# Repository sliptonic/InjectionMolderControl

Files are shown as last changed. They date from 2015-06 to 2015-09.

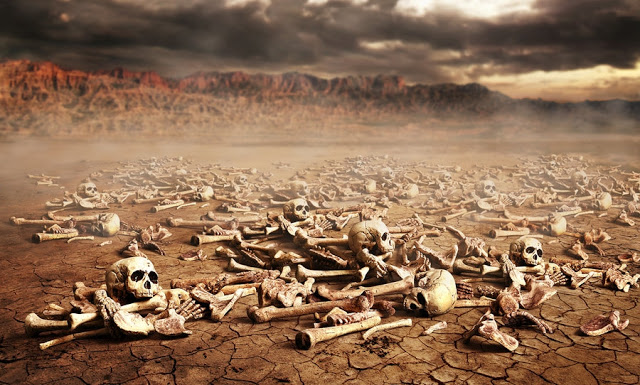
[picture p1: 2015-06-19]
termistortemp2/valley_of_dry_bones_.jpg

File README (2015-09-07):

Injection molder digital control 
Columbia Gadget Works (2015)

This is a control system for a hobby injection molder as described in "Secrets of Building a Plastic Injection Molding Machine" by Vincent R. Gingery.

In the book, he uses a simple thermostat to control a heater element.  We wanted to try something slightly more sophisticated so we built this.

The control is housed in a small project box.  It consists of an arduino Nano on a custom board and connected to:

Two tact switches on D11 and D12 for up/down control of the temperature set point.

A Sparkfun 7-segment serial lcd display (https://www.sparkfun.com/products/11440)  The display shows a:nnn for the actual temperature and p:nnn for the setpoint.

A 10k thermister for measuring temperature of the heater block.

A Sparkfun beefcake relay control kit. (https://www.sparkfun.com/products/11042)

#########################
Status:  
#########################
It works but the interface isn't very responsive.

#########################
TODO:  
#########################

Improve the loop that detects button pushes.  
Allow push/hold for inputing the temperature.

Improve the loop that controls temperature.  PID?

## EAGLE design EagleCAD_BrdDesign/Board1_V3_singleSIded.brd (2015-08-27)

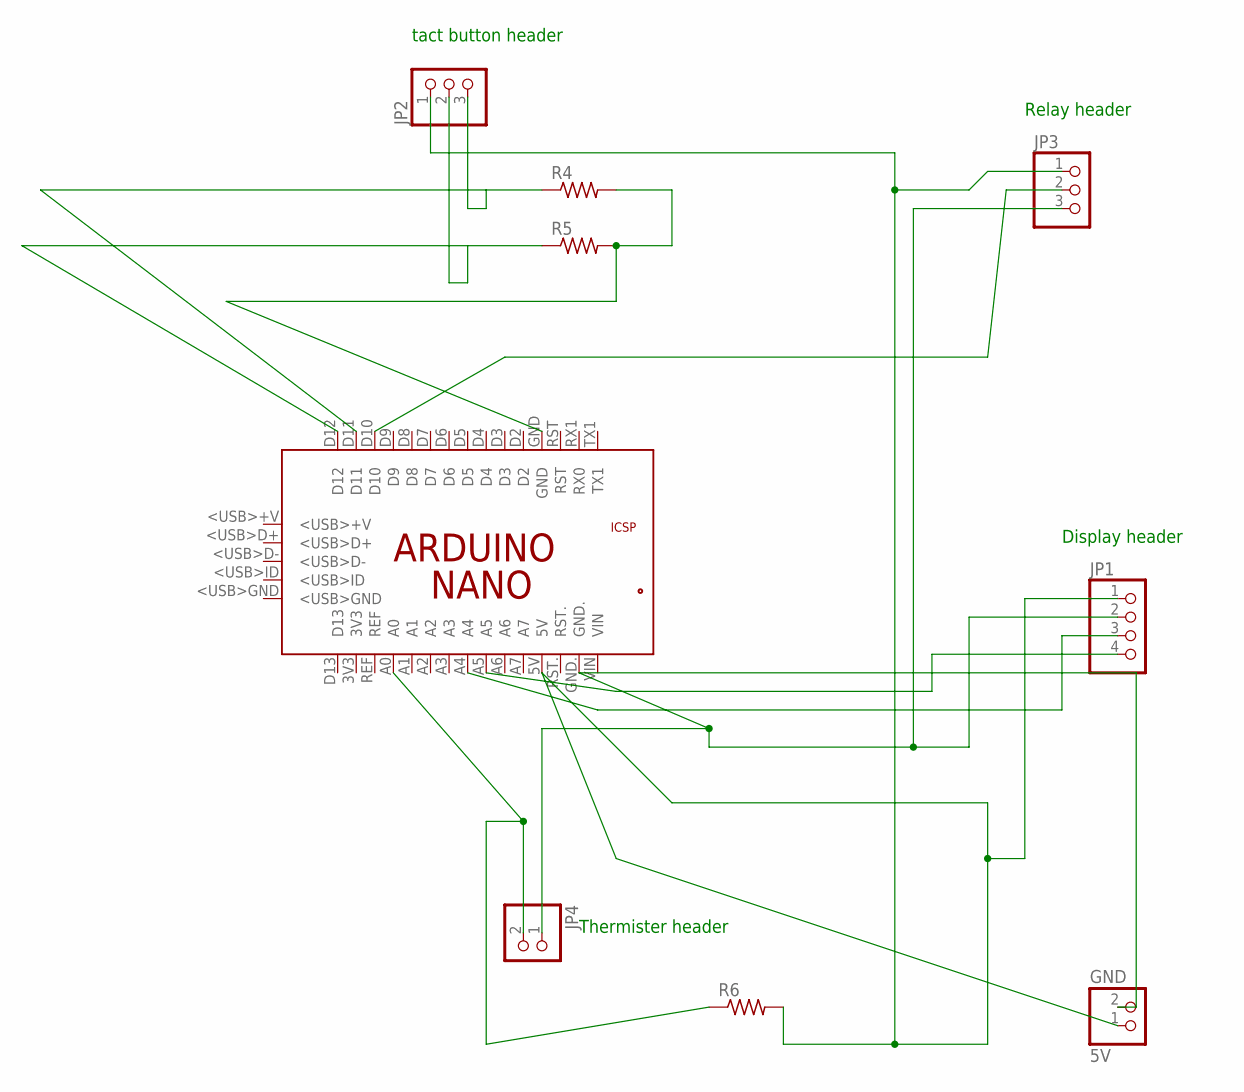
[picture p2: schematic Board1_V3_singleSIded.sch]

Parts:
5V: GND; 1X02/90
JP1: PINHD-1X4/90; 1X04/90
JP2, JP3: PINHD-1X3/90; 1X03/90
JP4: PINHD-1X2/90; 1X02/90
PCB1: ARDUINO_NANO
R4, R5: R-US_0207/10; 0207/10
R6: R-US_0207/15; 0207/15

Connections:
unnamed: JP2.2, PCB1.D12, R5.1
unnamed: JP4.2, PCB1.A0, R6.1
unnamed: JP3.2, PCB1.D10
unnamed: 5V.2, JP1.2, JP3.3, JP4.1, PCB1.GND.
unnamed: JP1.4, PCB1.A5
unnamed: JP1.3, PCB1.A4
unnamed: 5V.1, JP1.1, JP2.1, JP3.1, PCB1.5V, R6.2
unnamed: PCB1.GND, R4.2, R5.2
unnamed: JP2.3, PCB1.D11, R4.1

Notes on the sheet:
tact button header
Thermister header
Display header
Relay header

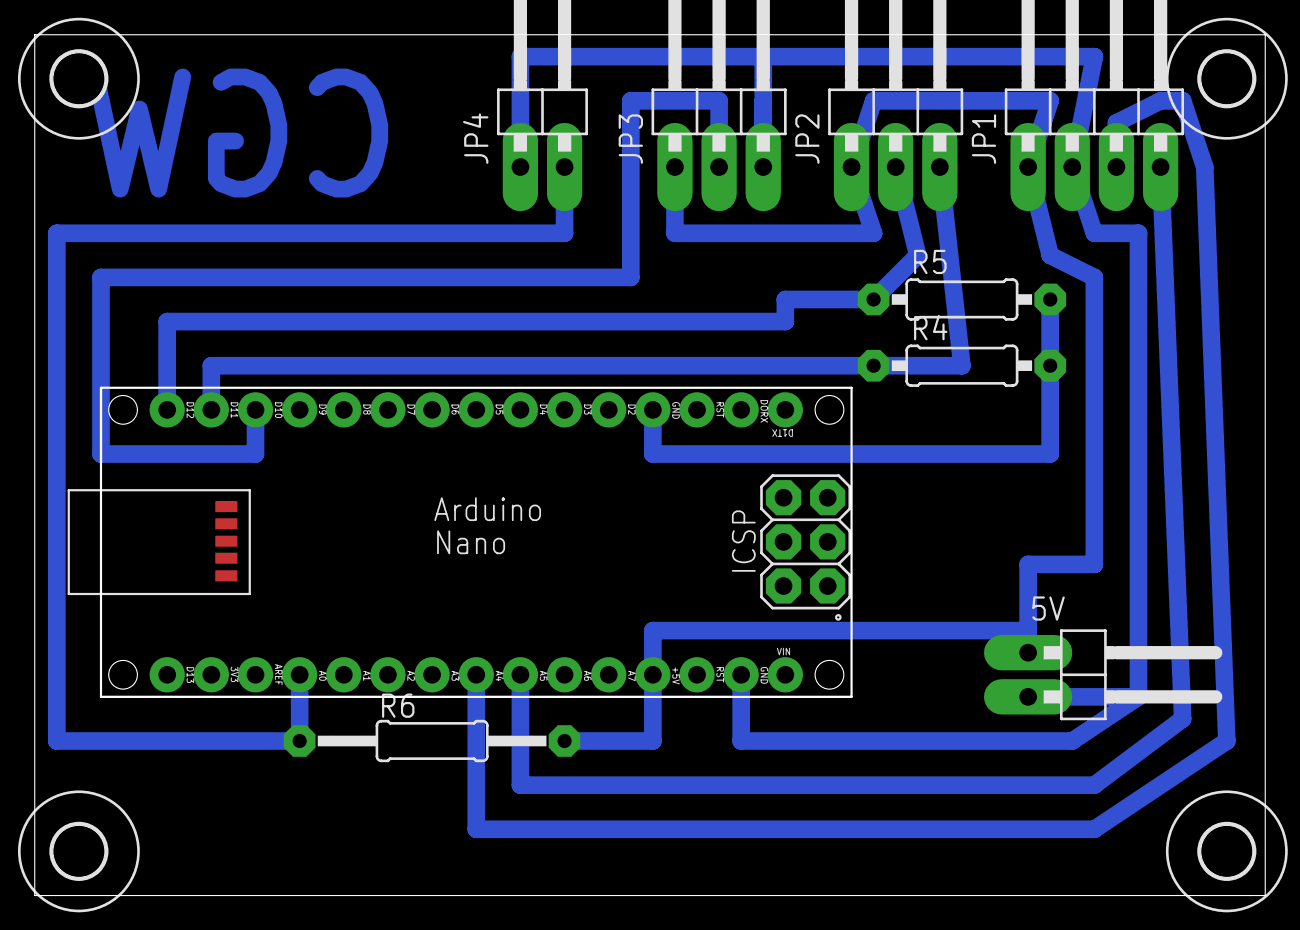
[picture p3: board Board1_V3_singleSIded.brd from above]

Board: 2 copper layers, 70.8 x 49.5 mm, 13 parts (0 on the bottom side), 9 nets.

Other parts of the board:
U$1, U$2, U$3, U$4: 3,0

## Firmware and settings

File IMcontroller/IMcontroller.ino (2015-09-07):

/* Serial 7-Segment Display Example Code

   Circuit:
   Arduino -------------- Serial 7-Segment
     5V   --------------------  VCC
     GND  --------------------  GND
     SDA  --------------------  SDA (A4 on older 'duino's)
     SCL  --------------------  SCL (A5 on older 'duino's)
*/
#include <Wire.h> // Include the Arduino SPI library

// Here we'll define the I2C address of our S7S. By default it
//  should be 0x71. This can be changed, though.
const byte s7sAddress = 0x71;


//Thermistor setup
// which analog pin to connect
#define THERMISTORPIN A0         
// resistance at 25 degrees C
#define THERMISTORNOMINAL 68000      
// temp. for nominal resistance (almost always 25 C)
#define TEMPERATURENOMINAL 31   
// how many samples to take and average, more takes longer
// but is more 'smooth'
#define NUMSAMPLES 5
// The beta coefficient of the thermistor (usually 3000-4000)
#define BCOEFFICIENT 3950
// the value of the 'other' resistor
#define SERIESRESISTOR 10000    

//which pin to connect relay control to
# define RELAYPIN 10
 
int samples[NUMSAMPLES];

//Here's some setup for checking the buttons
#define DEBOUNCE 10  // button debouncer, how many ms to debounce, 5+ ms is usually plenty

// here is where we define the buttons that we'll use. button "1" is the first, button "6" is the 6th, etc
byte buttons[] = {11, 12}; // the analog 0-5 pins are also known as 14-19
// This handy macro lets us determine how big the array up above is, by checking the size
#define NUMBUTTONS sizeof(buttons)
// we will track if a button is just pressed, just released, or 'currently pressed' 
byte pressed[NUMBUTTONS], justpressed[NUMBUTTONS], justreleased[NUMBUTTONS];

//char tempString[5];  // Will be used with sprintf to create strings
char tempString[5];


unsigned int setpoint = 175;
unsigned int actual_temp = 0;


//Some variables for debouncing the buttons
long lastDebounceTime = 0;  // the last time the output pin was toggled
long debounceDelay = 50;    // the debounce time; increase if the output flickers

void setup()
{
  byte i;
  Serial.begin(9600);
  Serial.print("Button checker with ");
  Serial.print(NUMBUTTONS, DEC);
  Serial.println(" buttons");
  
  
  // Make input & enable pull-up resistors on switch pins
  for (i=0; i < NUMBUTTONS; i++)
  {
    pinMode(buttons[i], INPUT);
    //digitalWrite(buttons[i], LOW);
  }

  pinMode(RELAYPIN, OUTPUT);

  Wire.begin();  // Initialize hardware I2C pins

  // Clear the display, and then turn on all segments and decimals
  clearDisplayI2C();  // Clears display, resets cursor

  // Greeting
  s7sSendStringI2C("-HI-");

  setBrightnessI2C(255);  // High brightness
  delay(1500);
  setDecimalsI2C(0b000001);  // Turn on first decimal to separate S/P from numbers.

  // Clear the display before jumping into loop
  sprintf(tempString, "p%03d", setpoint);
  s7sSendStringI2C(tempString);

}

void loop()
{
  check_switches(); //see if the button state has changed
  
  
  if (justpressed[0]) {
    setpoint += 5;     
    sprintf(tempString, "p%03d", setpoint);
    s7sSendStringI2C(tempString);
    delay(1500);
  } 
  
  if (justpressed[1]) {
    setpoint -= 5;    
    sprintf(tempString, "p%03d", setpoint);
    s7sSendStringI2C(tempString);
    delay(1500);
  } 

  actual_temp = gettemp();
  sprintf(tempString, "A%03d", actual_temp);
  s7sSendStringI2C(tempString);

  if (actual_temp >= (setpoint +5)) {
    //turn off the relay
    digitalWrite(RELAYPIN, LOW); 
  }
  else if (actual_temp <= (setpoint - 5)) {
    //turn on the relay
    digitalWrite(RELAYPIN, HIGH); 
  }
  delay(100);  // This will make the display update at 10Hz.*/
  
  
}

// This custom function works somewhat like a serial.print.
//  You can send it an array of chars (string) and it'll print
//  the first 4 characters in the array.
void s7sSendStringI2C(String toSend)
{
  Wire.beginTransmission(s7sAddress);
  for (int i=0; i<4; i++)
  {
    Wire.write(toSend[i]);
  }
  Wire.endTransmission();
}

// Send the clear display command (0x76)
//  This will clear the display and reset the cursor
void clearDisplayI2C()
{
  Wire.beginTransmission(s7sAddress);
  Wire.write(0x76);  // Clear display command
  Wire.endTransmission();
}

// Set the displays brightness. Should receive byte with the value
//  to set the brightness to
//  dimmest------------->brightest
//     0--------127--------255
void setBrightnessI2C(byte value)
{
  Wire.beginTransmission(s7sAddress);
  Wire.write(0x7A);  // Set brightness command byte
  Wire.write(value);  // brightness data byte
  Wire.endTransmission();
}

// Turn on any, none, or all of the decimals.
//  The six lowest bits in the decimals parameter sets a decimal 
//  (or colon, or apostrophe) on or off. A 1 indicates on, 0 off.
//  [MSB] (X)(X)(Apos)(Colon)(Digit 4)(Digit 3)(Digit2)(Digit1)
void setDecimalsI2C(byte decimals)
{
  Wire.beginTransmission(s7sAddress);
  Wire.write(0x77);
  Wire.write(decimals);
  Wire.endTransmission();
}


void check_switches()
//  Monitor the buttons and note changes in state so we can respond.

{
  static byte previousstate[NUMBUTTONS];
  static byte currentstate[NUMBUTTONS];
  static long lasttime;
  byte index;

  if (millis() < lasttime){ // we wrapped around, lets just try again
     lasttime = millis();
  }
  
  if ((lasttime + DEBOUNCE) > millis()) {
    // not enough time has passed to debounce
    return; 
  }

  // ok we have waited DEBOUNCE milliseconds, lets reset the timer
  lasttime = millis();
  
  for (index = 0; index < NUMBUTTONS; index++){
    currentstate[index] = digitalRead(buttons[index]);   // read the button
    
    if (currentstate[index] == previousstate[index]) {  //no change
      justpressed[index] = LOW;
      justreleased[index] = LOW;
    }
    
    if ((pressed[index] == LOW) && (currentstate[index] == HIGH)) {
          // pressed
          justpressed[index] = HIGH;
      }
    else if ((pressed[index] == HIGH) && (currentstate[index] == LOW)) {
          justreleased[index] = HIGH;
      }
  
    //set the pressed state and set previousstate so we see a change
    pressed[index] = currentstate[index];  
    previousstate[index] = currentstate[index];   
  }

}

int gettemp() {
  uint8_t i;
  float average;
 
  // take N samples in a row, with a slight delay
  for (i=0; i< NUMSAMPLES; i++) {
   samples[i] = analogRead(THERMISTORPIN);
   delay(10);
  }
 
  // average all the samples out
  average = 0;
  for (i=0; i< NUMSAMPLES; i++) {
     average += samples[i];
  }
  average /= NUMSAMPLES;
 
    // convert the value to resistance
  average = 1023 / average - 1;
  average = SERIESRESISTOR / average;
  
  float steinhart;
  steinhart = average / THERMISTORNOMINAL;     // (R/Ro)
  steinhart = log(steinhart);                  // ln(R/Ro)
  steinhart /= BCOEFFICIENT;                   // 1/B * ln(R/Ro)
  steinhart += 1.0 / (TEMPERATURENOMINAL + 273.15); // + (1/To)
  steinhart = 1.0 / steinhart;                 // Invert
  steinhart -= 273.15;                         // convert to C
 
  return steinhart;
}

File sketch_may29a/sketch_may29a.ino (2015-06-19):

#include <avr/pgmspace.h>

int led_state;
unsigned long time;

#define THERM_PIN   0  // 10ktherm & 10k resistor as divider.

//Thermistor lookup Table
//
// Small Version
/*
ADC   C
250,  1.4
275,  4.0
300,  6.4
325,  8.8
350,  11.1
375,  13.4
400,  15.6
425,  17.8
450,  20.0
475,  22.2
500,  24.4
525,  26.7
550,  29.0
575,  31.3
600,  33.7
625,  36.1
650,  38.7
675,  41.3
700,  44.1
725,  47.1
750,  50.2
775,  53.7
784,  55.0
825,  61.5
850,  66.2
875,  71.5
900,  77.9
925,  85.7
937,  90.3
950,  96.0
975,  111.2
1000, 139.5
*/

// Big lookup Table (approx 750 entries), subtract 238 from ADC reading to start at 0*C. Entries in 10ths of degree i.e. 242 = 24.2*C Covers 0*C to 150*C For 10k resistor/10k thermistor voltage divider w/ therm on the + side.
const int temps[] PROGMEM = { 0, 1, 2, 3, 4, 6, 7, 8, 9, 10, 11, 12, 13, 14, 15, 16, 17, 18, 19, 20, 21, 22, 24, 25, 26, 27, 28, 29, 30, 31, 32, 33, 34, 35, 36, 37, 38, 39, 40, 41, 42, 43, 44, 45, 46, 47, 48, 49, 50, 51, 52, 53, 54, 55, 56, 57, 58, 59, 60, 61, 62, 63, 64, 65, 66, 67, 68, 68, 69, 70, 71, 72, 73, 74, 75, 76, 77, 78, 79, 80, 81, 82, 83, 84, 85, 86, 87, 88, 88, 89, 90, 91, 92, 93, 94, 95, 96, 97, 98, 99, 100, 101, 102, 102, 103, 104, 105, 106, 107, 108, 109, 110, 111, 112, 113, 114, 114, 115, 116, 117, 118, 119, 120, 121, 122, 123, 124, 124, 125, 126, 127, 128, 129, 130, 131, 132, 133, 134, 134, 135, 136, 137, 138, 139, 140, 141, 142, 143, 143, 144, 145, 146, 147, 148, 149, 150, 151, 151, 152, 153, 154, 155, 156, 157, 158, 159, 159, 160, 161, 162, 163, 164, 165, 166, 167, 167, 168, 169, 170, 171, 172, 173, 174, 175, 175, 176, 177, 178, 179, 180, 181, 182, 182, 183, 184, 185, 186, 187, 188, 189, 190, 190, 191, 192, 193, 194, 195, 196, 197, 197, 198, 199, 200, 201, 202, 203, 204, 205, 205, 206, 207, 208, 209, 210, 211, 212, 212, 213, 214, 215, 216, 217, 218, 219, 220, 220, 221, 222, 223, 224, 225, 226, 227, 228, 228, 229, 230, 231, 232, 233, 234, 235, 235, 236, 237, 238, 239, 240, 241, 242, 243, 243, 244, 245, 246, 247, 248, 249, 250, 251, 252, 252, 253, 254, 255, 256, 257, 258, 259, 260, 260, 261, 262, 263, 264, 265, 266, 267, 268, 269, 269, 270, 271, 272, 273, 274, 275, 276, 277, 278, 279, 279, 280, 281, 282, 283, 284, 285, 286, 287, 288, 289, 289, 290, 291, 292, 293, 294, 295, 296, 297, 298, 299, 300, 301, 301, 302, 303, 304, 305, 306, 307, 308, 309, 310, 311, 312, 313, 314, 315, 315, 316, 317, 318, 319, 320, 321, 322, 323, 324, 325, 326, 327, 328, 329, 330, 331, 332, 333, 334, 335, 335, 336, 337, 338, 339, 340, 341, 342, 343, 344, 345, 346, 347, 348, 349, 350, 351, 352, 353, 354, 355, 356, 357, 358, 359, 360, 361, 362, 363, 364, 365, 366, 367, 368, 369, 370, 371, 372, 373, 374, 375, 376, 377, 378, 379, 380, 381, 382, 383, 384, 385, 386, 387, 388, 389, 390, 392, 393, 394, 395, 396, 397, 398, 399, 400, 401, 402, 403, 404, 405, 406, 407, 408, 410, 411, 412, 413, 414, 415, 416, 417, 418, 419, 420, 422, 423, 424, 425, 426, 427, 428, 429, 430, 432, 433, 434, 435, 436, 437, 438, 439, 441, 442, 443, 444, 445, 446, 448, 449, 450, 451, 452, 453, 455, 456, 457, 458, 459, 460, 462, 463, 464, 465, 466, 468, 469, 470, 471, 472, 474, 475, 476, 477, 479, 480, 481, 482, 484, 485, 486, 487, 489, 490, 491, 492, 494, 495, 496, 498, 499, 500, 501, 503, 504, 505, 507, 508, 509, 511, 512, 513, 515, 516, 517, 519, 520, 521, 523, 524, 525, 527, 528, 530, 531, 532, 534, 535, 537, 538, 539, 541, 542, 544, 545, 547, 548, 550, 551, 552, 554, 555, 557, 558, 560, 561, 563, 564, 566, 567, 569, 570, 572, 574, 575, 577, 578, 580, 581, 583, 585, 586, 588, 589, 591, 593, 594, 596, 598, 599, 601, 603, 604, 606, 608, 609, 611, 613, 614, 616, 618, 620, 621, 623, 625, 627, 628, 630, 632, 634, 636, 638, 639, 641, 643, 645, 647, 649, 651, 653, 654, 656, 658, 660, 662, 664, 666, 668, 670, 672, 674, 676, 678, 680, 683, 685, 687, 689, 691, 693, 695, 697, 700, 702, 704, 706, 708, 711, 713, 715, 718, 720, 722, 725, 727, 729, 732, 734, 737, 739, 741, 744, 746, 749, 752, 754, 757, 759, 762, 764, 767, 770, 773, 775, 778, 781, 784, 786, 789, 792, 795, 798, 801, 804, 807, 810, 813, 816, 819, 822, 825, 829, 832, 835, 838, 842, 845, 848, 852, 855, 859, 862, 866, 869, 873, 877, 881, 884, 888, 892, 896, 900, 904, 908, 912, 916, 920, 925, 929, 933, 938, 942, 947, 952, 956, 961, 966, 971, 976, 981, 986, 991, 997, 1002, 1007, 1013, 1019, 1024, 1030, 1036, 1042, 1049, 1055, 1061, 1068, 1075, 1082, 1088, 1096, 1103, 1110, 1118, 1126, 1134, 1142, 1150, 1159, 1168, 1177, 1186, 1196, 1206, 1216, 1226, 1237, 1248, 1260, 1272, 1284, 1297, 1310, 1324, 1338, 1353, 1369, 1385, 1402, 1420, 1439, 1459, 1480, 1502 };


void setup() {
  pinMode(13, OUTPUT);
  Serial.begin(9600);
  time=millis();
Serial.println("Ready");

}

void loop() { 

int therm;   
therm=analogRead(THERM_PIN)-238;
therm=pgm_read_word(&temps[therm]);

Serial.println(therm, DEC);

if (millis() - time >1000){   
time=millis();
digitalWrite(13,led_state);
led_state=!led_state;
}

}

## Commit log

2015-07-17 thermistor readings reasonable now. Integrated to main project sketch file
2015-08-19 board layout
    [Board1_V4.brd, Board1_V4.sch]
2015-08-26 eagle board design
    [Board1_V3_singleSIded.brd, Board1_V3_singleSIded.sch]
2015-08-26 board updated
    Added resistors
2015-08-26 gcode for making board
2015-09-07 Added basic control of Beefcake relay.
    Edited README
    TODO: improve input and control loop.
